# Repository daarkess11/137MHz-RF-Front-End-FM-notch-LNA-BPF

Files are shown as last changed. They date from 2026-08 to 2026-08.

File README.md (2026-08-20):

# 137MHz-VHF-Front-End (Work-in-Progress)

137.5 MHz VHF Downlink RF Front-End for satellite ground stations.

## Quick specs

| Parameter | Value |
|---|---|
| Target frequency | 137.5 MHz VHF Downlink (NOAA-15/18/19, Meteor-M) |
| Active device | PGA-103+ E-PHEMT MMIC |
| Cascaded gain (S21) | 22 dB @ 137 MHz |
| Noise Figure (NF) | ~1.84 dB *(simulation/analytical estimate only, not experimentally measured!!)* |
| Out-of-band rejection (88–108 MHz) | -33.3 dB to -48.8 dB (cascaded) |
| Stability | Unconditionally stable 10 MHz – 4 GHz (R+L shunt)¹ |
| PCB | CPWG (50 Ω), W=1.25mm, H=1.6mm, S=0.24mm, εr=4.5, t=1oz (35µm) |

¹*Above the available .s2p model limits, the stability curves rely on simulator extrapolation and should be treated as indicative rather than physically validated results. See the stability section in the full report for the modelling limitations.*

## Design Approach

- **Simulation:** QUCS-S with real component S-parameters
- **Validation:** Experimental VNA testing pending
- **EM simulation:** Not performed (CPWG geometry validated with calculator/published formulas at 137 MHz)
## Repo structure

- [`/Simulation`](./Simulation) QUCS-S files and .s2p models
- [`/hardware`](./hardware) — KiCad project files + BOM list
  
Below is a quick summary with the PCB render from KiCad and a couple of screenshots from QUCS-S with the simulation results and schematics.

## ⚠️ Prototype Status

The design has been fully simulated and theoretically verified. Experimental verification will follow once the PCB has been fabricated and tested with a VNA.

# Screenshots
*Note: I used .s2p files from the manufacturer datasheets for the simulations, not ideal component models, ideal symbols only show up when they make the schematic easier to read.*

### PCB
137MHz_RF_FrontEnd
137MHz_RF_FrontEndvias

### S[2,1] graphic and measures (only up to 600MHz for a better view, check /docs if you want to see higher frequencies)


### Stability


## Schematics
### Cauer Notch 
Captura4_Nero_AI_Image_Upscaler_Photo_Face

### LNA


### Band-Pass Butterworth


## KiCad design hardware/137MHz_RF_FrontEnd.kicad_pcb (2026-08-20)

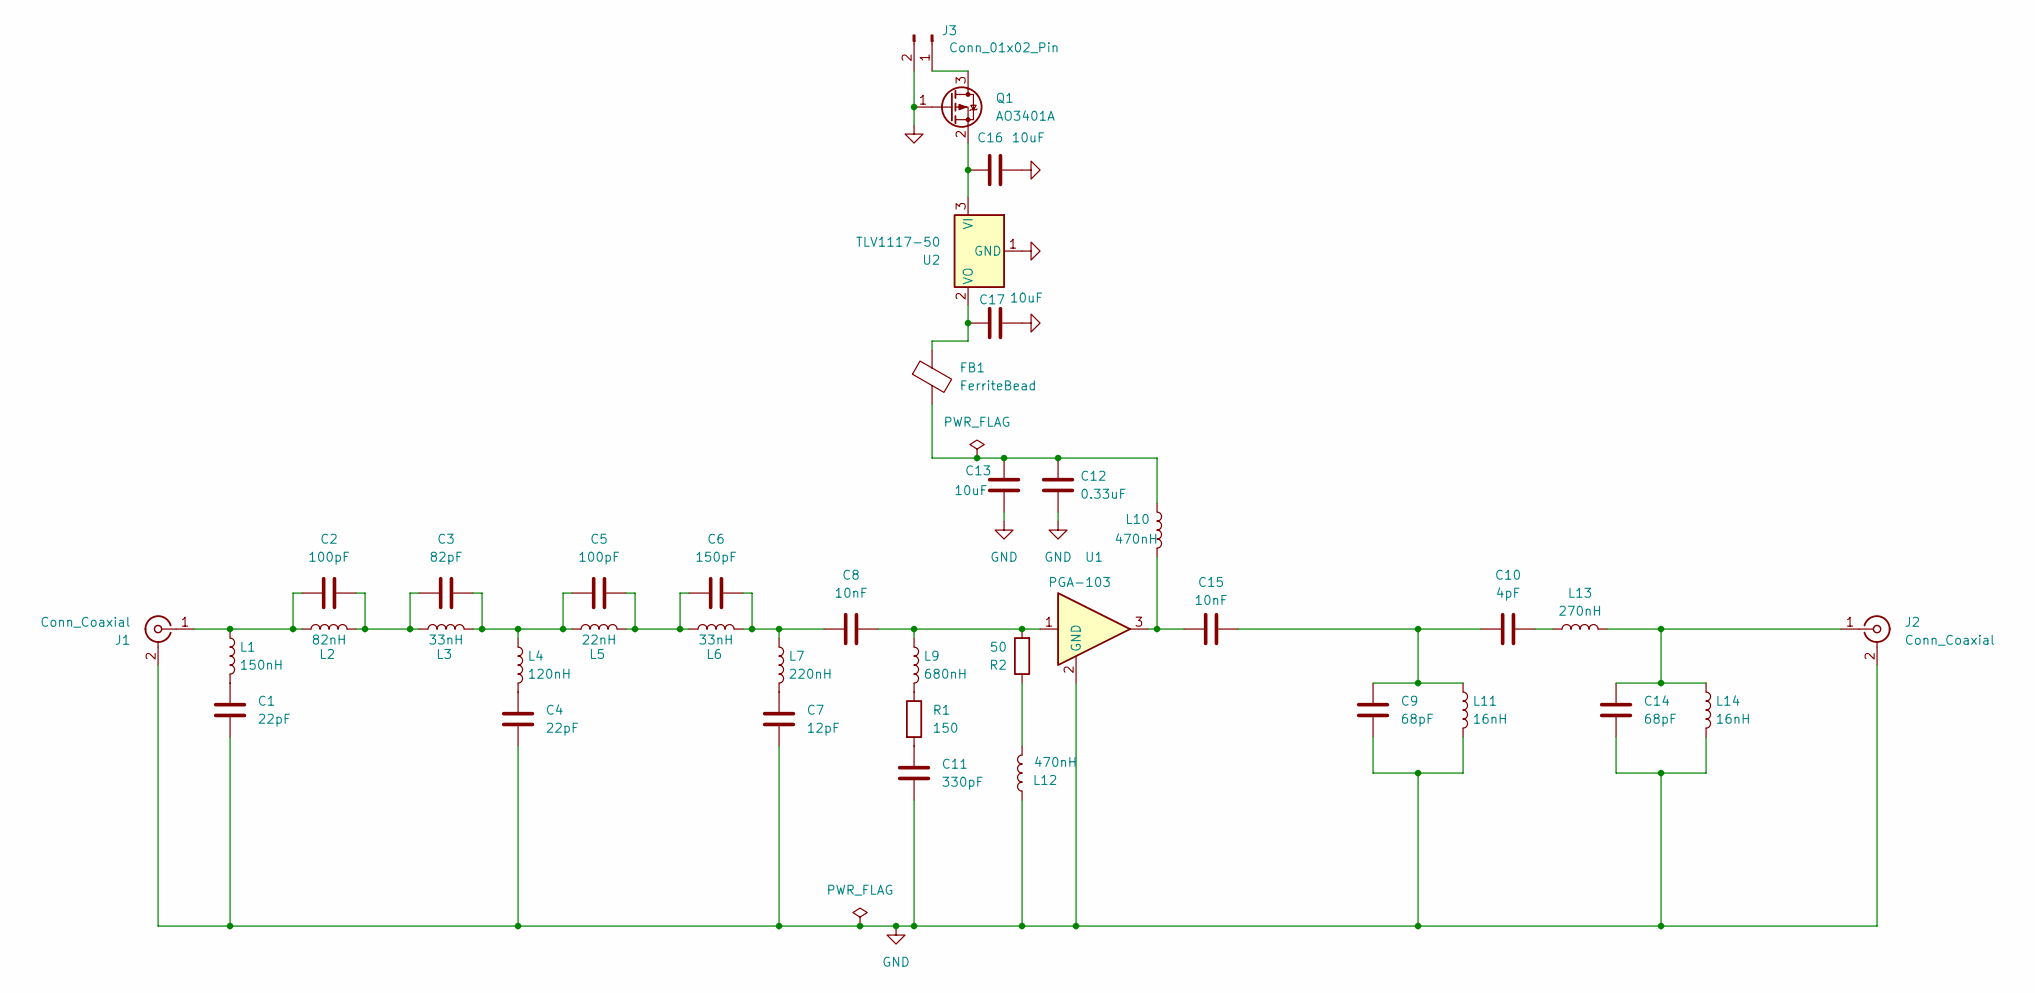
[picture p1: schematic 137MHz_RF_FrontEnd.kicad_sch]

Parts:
C1, C4: 22pF; C_0603_1608Metric_Pad1.08x0.95mm_HandSolder
C2, C5: 100pF; C_0603_1608Metric_Pad1.08x0.95mm_HandSolder
C3: 82pF; C_0603_1608Metric_Pad1.08x0.95mm_HandSolder
C6: 150pF; C_0603_1608Metric_Pad1.08x0.95mm_HandSolder
C7: 12pF; C_0603_1608Metric_Pad1.08x0.95mm_HandSolder
C8, C15: 10nF; C_0603_1608Metric_Pad1.08x0.95mm_HandSolder
C9, C14: 68pF; C_0603_1608Metric_Pad1.08x0.95mm_HandSolder
C10: 4pF; C_0603_1608Metric_Pad1.08x0.95mm_HandSolder
C11: 330pF; C_0603_1608Metric_Pad1.08x0.95mm_HandSolder
C12: 0.33uF; C_0805_2012Metric_Pad1.18x1.45mm_HandSolder
C13, C16, C17: 10uF; C_0805_2012Metric_Pad1.18x1.45mm_HandSolder
FB1: FerriteBead; L_0805_2012Metric_Pad1.05x1.20mm_HandSolder
J1, J2: Conn_Coaxial; SMA_Amphenol_132289_EdgeMount
J3: Conn_01x02_Pin; JST_XH_S2B-XH-A-1_1x02_P2.50mm_Horizontal
L1: 150nH; L_0603_1608Metric_Pad1.05x0.95mm_HandSolder
L2: 82nH; L_0603_1608Metric_Pad1.05x0.95mm_HandSolder
L3, L6: 33nH; L_0603_1608Metric_Pad1.05x0.95mm_HandSolder
L4: 120nH; L_0603_1608Metric_Pad1.05x0.95mm_HandSolder
L5: 22nH; L_0603_1608Metric_Pad1.05x0.95mm_HandSolder
L7: 220nH; L_0603_1608Metric_Pad1.05x0.95mm_HandSolder
L9: 680nH; L_0805_2012Metric_Pad1.05x1.20mm_HandSolder
L10, L12: 470nH; L_0805_2012Metric_Pad1.05x1.20mm_HandSolder
L11, L14: 16nH; L_0603_1608Metric_Pad1.05x0.95mm_HandSolder
L13: 270nH; L_0603_1608Metric_Pad1.05x0.95mm_HandSolder
Q1: AO3401A; SOT-23
R1: 150; R_0603_1608Metric_Pad0.98x0.95mm_HandSolder
R2: 50; R_0603_1608Metric_Pad0.98x0.95mm_HandSolder
U1: PGA-103; SOT-89-3
U2: TLV1117-50; SOT-223

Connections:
GND: C1.2, C4.2, C7.2, C9.2, C11.2, C12.2, C13.2, C14.2, C16.2, C17.2, J1.2 (Ext), J2.2 (Ext), J3.2, L11.2, L12.1, L14.2, Q1.1 (G), U1.2 (GND_2), U2.1 (GND)
unnamed: C1.1, L1.2
unnamed: C2.1, C3.2, L2.2, L3.1
unnamed: C3.1, C5.2, L3.2, L4.1, L5.1
unnamed: C4.1, L4.2
unnamed: C5.1, C6.2, L5.2, L6.1
unnamed: C6.1, C8.2, L6.2, L7.1
unnamed: C7.1, L7.2
unnamed: C8.1, L9.1, R2.2, U1.1
unnamed: C10.1, L13.1
unnamed 10: C9.1, C10.2, C15.1, L11.1; also elsewhere on the board
unnamed: C11.1, R1.2
unnamed 12: C12.1, C13.1, FB1.2, L10.1; also elsewhere on the board
unnamed 13: C15.2, L10.2, U1.3; also elsewhere on the board
unnamed: C2.2, J1.1 (In), L1.1, L2.1
unnamed: C14.1, J2.1 (In), L13.2, L14.1
unnamed: J3.1, Q1.3 (D)
unnamed: L9.2, R1.1
unnamed: L12.2, R2.1
unnamed: C16.1, Q1.2 (S), U2.3 (VI)
unnamed: C17.1, FB1.1, U2.2 (VO), U2.4

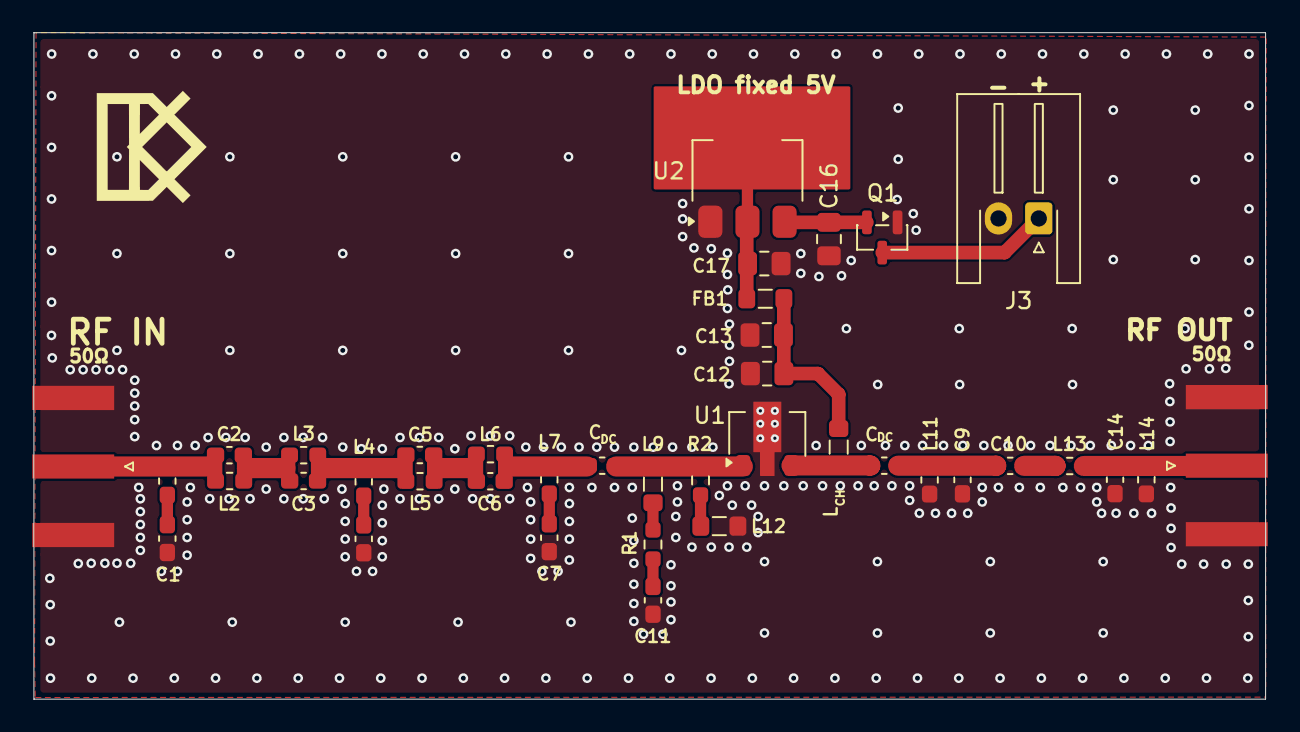
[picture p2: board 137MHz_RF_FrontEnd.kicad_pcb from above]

Board: 2 copper layers, 76.4 x 41.3 mm, 40 parts (0 on the bottom side), 21 nets.

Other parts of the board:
-: -; LOGO
C: 10nF; C_0603_1608Metric_Pad1.08x0.95mm_HandSolder
L: 470nH; L_0805_2012Metric_Pad1.05x1.20mm_HandSolder

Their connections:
unnamed 10: C.1; also elsewhere on the board
unnamed 12: L.1; also elsewhere on the board
unnamed 13: C.2, L.2; also elsewhere on the board

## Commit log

2026-08-13 Update print statement from 'Hello' to 'Goodbye'
2026-08-13 Upload KiCad hardware files
    [137MHz_RF_FrontEnd.kicad_pcb, 137MHz_RF_FrontEnd.kicad_sch]
2026-08-13 Update README with project details and cautionary note
    Added project summary and advice for users regarding PCB manufacturing.
2026-08-13 Revise PCB ordering advice in README
    Updated advice section to emphasize caution before ordering PCBs.
2026-08-13 137MHz whole project
    [137MHz-VHF.sch, 137MHz_RF_FrontEnd.kicad_pcb, 137MHz_RF_FrontEnd.kicad_sch]
2026-08-13 Create VHF Satellite Ground Station LNA Stage - RF Design, Simulation and Engineering Report.pdf
2026-08-13 Update warning about ordering PCB in README
2026-08-13 Update README with PCB summary and simulation images
    Added a quick summary of the PCB and simulation results, including images and stability measures.
2026-08-13 Update README with new schematics
    Added schematics for Cauer Notch, LNA, and Band-Pass Butterworth.
2026-08-13 Update Schematics section in README
2026-08-13 Simplify warning about PCB manufacturing
    Removed the word 'castaña' to simplify the message about potential redesigns.
2026-08-13 Revise prototype status and testing notes
    Updated prototype status section to clarify that the project is still in testing and specifications are simulation-based. Added a note about pending real-world performance testing.
2026-08-14 Update VHF Satellite Ground Station LNA Stage - RF Design, Simulation and Engineering Report.pdf
2026-08-15 Update & applied changes
    [137MHz_RF_FrontEnd.kicad_pcb, 137MHz_RF_FrontEnd.kicad_sch, BOM.xlsx]
2026-08-16 updated values of L
    [137MHz_RF_FrontEnd.kicad_pcb]
2026-08-20 update PCB
    [137MHz_RF_FrontEnd.kicad_pcb]
